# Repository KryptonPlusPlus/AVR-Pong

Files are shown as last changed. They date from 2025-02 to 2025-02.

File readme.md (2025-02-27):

<div align="center">

# AVR Pong
</div>

## 💻 Sobre o projeto

Jogo Pong de um jogador em um microcontrolador avr (atmega328pa) exibindo a imagem em um monitor vga de resolução 640x480 60Hz de tela visível.

Veja uma documentação não finalizada [aqui](documentation/doc/main.pdf).

> [!WARNING]
> Para aumentar a compatibilidade com os monitores foi utilizado um sistema de clock de 25.175MHz, superior ao limite recomendado pelo fabricante de 20MHz.

# :scroll: Sumário

- [Funcionalidades](#⚙️-Funcionalidades)
- [Imagens](#🎨-Imagens)

## ⚙️ Funcionalidades

- [ ] Colisão com os paddles.
    - [x] Tratar a colisão do eixo x.
    - [ ] Alterar a direção e/ou inclinação do eixo y da bola no momento da colisão com o paddle.
- [x] Aceleração da bola ao decorrer do jogo.
- [x] Reiniciar o jogo após errar a bola e apertar um botão.
- [ ] Pontuação dos jogadores.
- [ ] Som.
- [ ] Switch para realizar configurações internas.
- [ ] Indutor e capacitor no _AVCC_ para reduzir ruídos (pag. 213 do datasheet)

## 🎨 Imagens

<details>

<summary>Imagens da montagem do circuito na protoboard:</summary>

<p align="center">
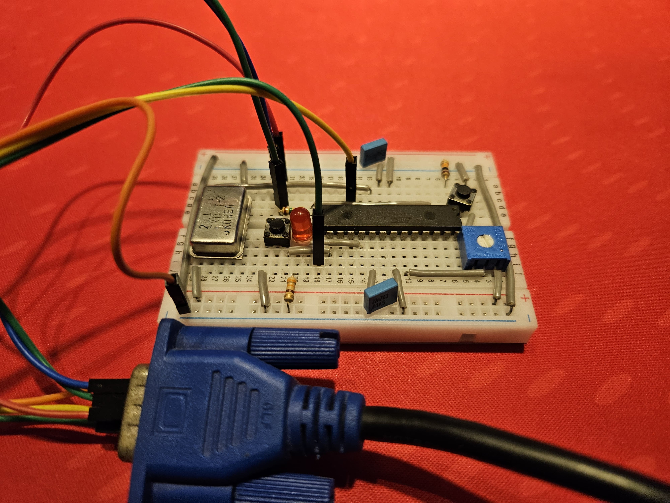
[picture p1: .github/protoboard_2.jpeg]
protoboard 1
    
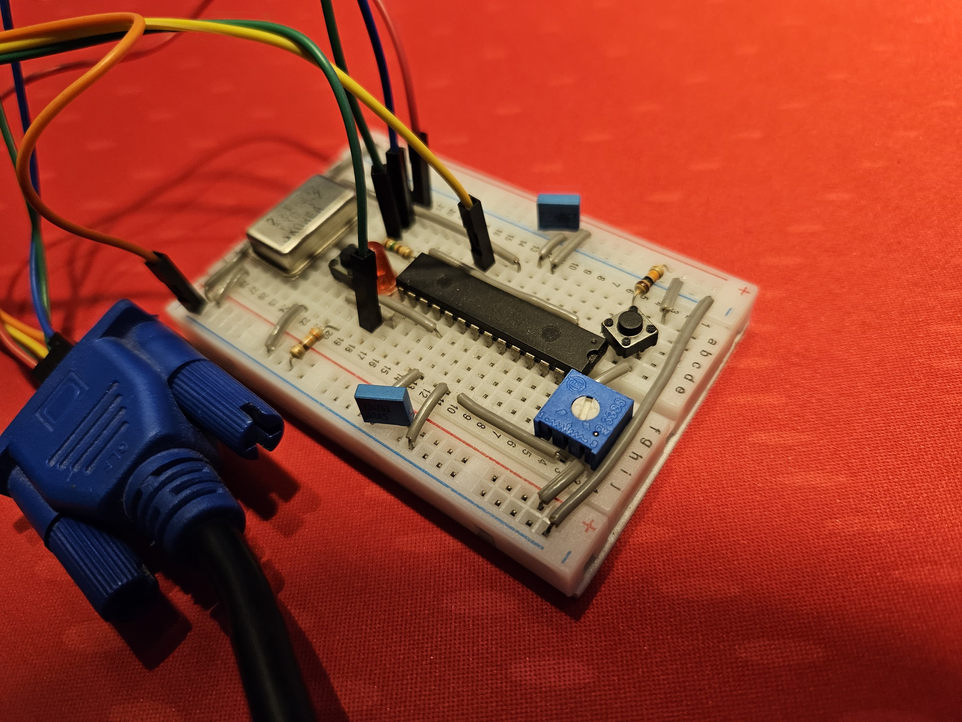
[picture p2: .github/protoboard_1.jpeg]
protoboard 2
    
</p>

> O _trimpot_ foi utilizado para movimentar o _paddle_ do jogador.

</details>

<details>

<summary>Imagem da renderização da tela no monitor vga:</summary>

<p align="center">
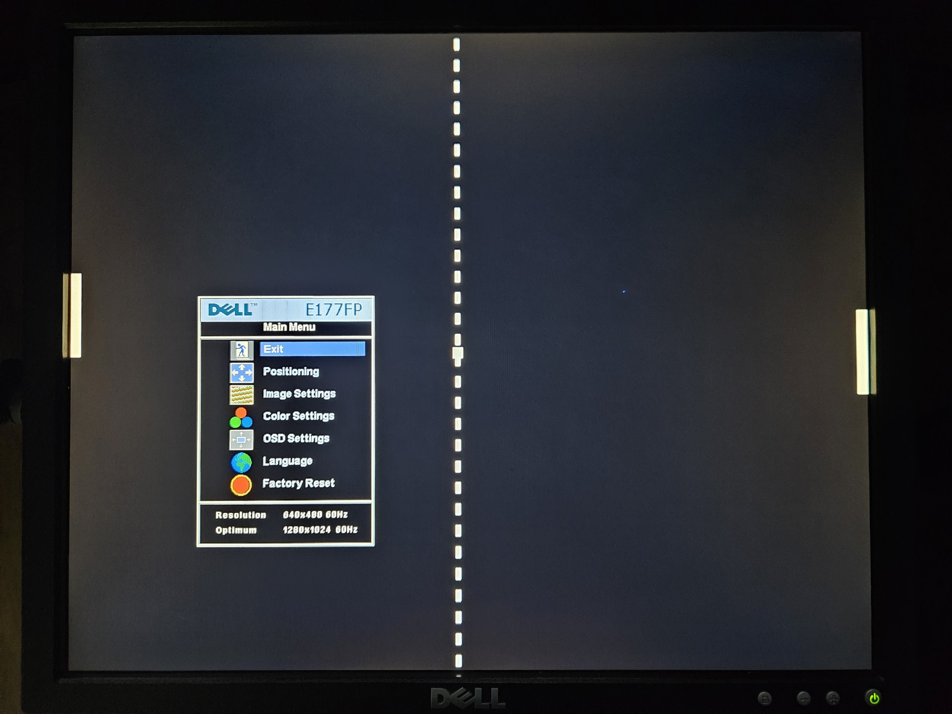
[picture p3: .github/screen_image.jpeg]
monitor
    
</p>

> Na imagem da renderização da tela existe uma linha vertical que não aparece, pois foi feita uma centralização da imagem pelas configurações no monitor, proveniente do fato da transferência dos dados das cores ser feita utilizando o _USART_ no modo _Master SPI_, já que quando ele está inativo possui nível lógico alto.

</details>

<details>

<summary>Imagem do esquemático:</summary>
<p align="center">
    monitor
</p>

</details>

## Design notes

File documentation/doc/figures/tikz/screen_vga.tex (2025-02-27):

\begin{figure}[H]
\centering
\resizebox{0.45\textwidth}{!}
{
\begin{tikzpicture}[x = .1mm, y = .1mm]
    
    \def\hvisiblearea {640}
    \def\vvisiblearea {480}
    
    \def\hfrontporch {16 * 2} % alterado para ficar mais estetico
    \def\vfrontporch {10 * 2} %

    \def\hsyncpulse {96}
    \def\vsyncpulse {2 * 4} % alterado para ficar mais estetico

    \def\hbackporch {48}
    \def\vbackporch {33}

    \begin{scope}[xshift = 5mm, local bounding box = pulse horizontal]
        \draw [black] (0, 0) -- ++(\hvisiblearea + \hfrontporch, 0) -- ++(0, -3.5mm) -- ++(\hsyncpulse, 0) -- ++(0, 3.5mm) -- ++(\hbackporch, 0);
        \node [above, font = \small] at (\hvisiblearea / 2, 0) {Pulso de sincronismo horizontal};
    \end{scope}

    \begin{scope}[yshift = -5mm, local bounding box = pulse vertical]
        \draw [black] (0, 0) -- ++(0, -\vvisiblearea - \vfrontporch) -- ++(3.5mm, 0) -- ++(0, -\vsyncpulse) -- ++(-3.5mm, 0) -- ++(0, -\vbackporch);
        \node [above, font = \small, rotate = 90] at (0, -\vvisiblearea / 2) {Pulso de sincronismo vertical};
    \end{scope}
    
    \begin{scope}[xshift = 5mm, yshift = -5mm, local bounding box = screen]
        % visible area
        \draw [black] (0, -\vvisiblearea) -- ++(\hvisiblearea, 0) -- ++(0, \vvisiblearea);
        % front porch
        \draw [black] (0, -\vvisiblearea - \vfrontporch) -- ++(\hvisiblearea + \hfrontporch, 0) -- ++(0, \vvisiblearea + \vfrontporch);
        % sync pulse
        \draw [black] (0, -\vvisiblearea - \vfrontporch - \vsyncpulse) -- ++(\hvisiblearea + \hfrontporch + \hsyncpulse, 0) -- ++(0, \vvisiblearea + \vfrontporch + \vsyncpulse);
        % back porch
        \draw [black] (0, 0) rectangle ++ (\hbackporch + \hvisiblearea + \hfrontporch + \hsyncpulse, -\vbackporch - \vvisiblearea - \vfrontporch - \vsyncpulse);
    
        %
        \node[above right = 0.8mm, font = \small, rotate = 90] at (\hvisiblearea, -\vvisiblearea) {\textit{Visible Area}};
        \node[above right = 0.8mm, font = \small, rotate = 90] at (\hvisiblearea + \hfrontporch, -\vvisiblearea) {\textit{Front Porch}};
        \node[above right = 0.8mm, font = \small, rotate = 90] at (\hvisiblearea + \hfrontporch + \hsyncpulse, -\vvisiblearea) {\textit{Sync Pulse}};
        \node[above right = 0.8mm, font = \small, rotate = 90] at (\hvisiblearea + \hfrontporch + \hsyncpulse + \hbackporch, -\vvisiblearea) {\textit{Back Porch}};
    \end{scope}

    \draw [gray, fill opacity = 0.5] (5mm,   -7.5mm) -- ++(0,    5mm);
    \draw [gray, fill opacity = 0.5] (7.5mm, -5mm)   -- ++(-5mm, 0);
\end{tikzpicture}
}
\caption{Regiões de varredura da tela}
\end{figure}

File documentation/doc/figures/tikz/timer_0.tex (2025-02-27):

\begin{figure}[H]
    \centering
    % https://wiki.physik.uzh.ch/cms/latex:tikz:electromagnetic_wave
    % https://tex.stackexchange.com/questions/550352/how-to-draw-a-simple-sine-square-sawtooth-waveform-in-latex
    \begin{tikzpicture}[line cap = round, line join = round, quotas/.style={very thin, |<->|}]
        %
        \def\Period{0.6\linewidth}
        \def\RampAmplitude{2.0}
        %
        \def\VericalOne{0.75 * \Period}
        \def\VericalTwo{\Period}

        % ramp
        \begin{scope}[local bounding box = ramp]
            \node [anchor = east, text width = 2cm, font = \small\itshape\bfseries] at (0, -\RampAmplitude) {tcnt0};
            \foreach \it/\txt in {0/ocr0a, -0.5/ocr0b, -2/bottom}
            {
                \draw [very thin, dotted] (0, \it) -- ++(1.16 * \Period, 0);
                \node [anchor = east, font = \footnotesize\itshape] at (0, \it) {\txt};
            }
   
            \draw (0, -\RampAmplitude) -- ++(\Period, \RampAmplitude) -- ++(0, -\RampAmplitude) -- ++(0.16 * \Period, 0.16 * \RampAmplitude);

        \end{scope}
        % pulse
        \begin{scope}[yshift = -2.5cm, local bounding box = pulse]
            \node [anchor = east, text width = 2cm, font = \small\itshape\bfseries] at (0, 0) {oc0b};
            \draw (0, 0) {-- ++(\VericalOne, 0) -- ++(0, -1) -- ++(\Period - \VericalOne, 0) -- ++(0, 1) -- ++(0.16 * \Period, 0)};
        \end{scope}

        \def\lastx{0}
        \foreach[count = \i, remember = \it as \lastxit] \it/\initpos in {\VericalOne/-0.5,\VericalTwo/0}
        {
             \draw [very thin, dotted] (\it, \initpos) -- (\it,   -4);
             \draw [very thin, dotted] (\it, \initpos) -- (\it,   -4);
             \draw [quotas] (\lastxit, -4) -- node[inner sep = 1pt, fill = white, font = \scriptsize] {\i} (\it,  -4);
        }
    \end{tikzpicture}
    \caption{Funcionamento do \textit{Timer 0} (\textit{Hsync})}
    \label{fig:timer-0}
\end{figure}

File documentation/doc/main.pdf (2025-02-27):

## AVR Pong

KrpytonPlusPlus

27 de fevereiro de 2025

## 1 Introdução

Esse projeto visa projetar um clone do jogo Pong em um microcontrolador avr utilizando o padrão de comunicação vga para exibir a imagem em um monitor.
Para isso foi dimensionado os ciclos de cpu para comportar o envio das informações de varredura dos pixels e os ciclos sobressalentes foram utilizados para carregar os dados para os buffers com as cores de cada pixel em uma linha (preto ou branco) e fazer o tratamento das iterações do jogo.
Buscando facilitar os cálculos e aumentar a compatibilidade com os monitores foi utilizado um sistema de clock de 25,175MHz para o microcontrolador superior ao limite estipulado pelo fabricante no manual, porém como vai ser visto adiante é a mesma frequência de sinal utilizada pelo monitor para gerar a imagem.

## 2 VGA (Video Graphics Array)

### 2.1 Regiões de varredura

Pulso de sincronismo horizontal

Pulso de sincronismo vertical

Visible Area
Front Porch
Sync Pulse

Back Porch

Figura 1: Regiões de varredura da tela

No monitor normalmente a Back Porch vem antes da Visible Area, porém para facilitar a apresentação e por ser um sinal cíclico foi apresentada no final. Para facilitar a visualização as dimensões de cada região não estão proporcionais aos valores reais.

Pixels
| Horizontal | Vertical
Back Porch | 48 | 33
Visible Area | 640 | 480
Front Porch | 16 | 10
Sync Pulse | 96 | 2
Total | 800 | 525

Tabela 1: Dimensão horizontal e vertical em pixels da tela para cada região de varredura

Normalmente os dados apresentados na tabela 1 são dados em micro segundos e quantidade de linhas, para a dimensão horizontal e vertical, respectivamente.

### 2.2 Pulsos de sincronismo

Os pulsos verticais são formados utilizando o Timer 1 no modo fast pwm com top sendo o icr1 (wgm1[3:0] = 1410) e utilizando um prescaling com valor 8 (cs1[2:0] = 210), a escolha desse Timer foi feita pelo fato de possuir um contador de 16 bits. O timer possui 3 registradores de comparação (ocr1a, ocr1b e icr1), sendo dois de saída, para poder realizar a construção do pulso, utilizando o modo de comparação para quando o contador atingir o valor de ocr1a a saída ir para nível lógico baixo e quando voltar para bottom ir para nível lógico alto (com1a[1:0] = 210) e o terceiro, de entrada, para determinar o inicio da área visível da tela.

tcnt1

icr1
ocr1a

ocr1b
bottom
oc1a
1 | 2 | 3

Figura 2: Funcionamento do Timer 1 (Vsync)

Na figura é possível ver o funcionamento esperado da saída oc1a em função do contador tcnt1, as regiões 1, 2 e 3 são respectivamente, Vertical Back Porch, Vertical Visible Area junto com a Vertical Front Porch e Vertical Sync Pulse.

Os valores de comparação da contagem são dados a seguir:

icr1 | 52499
ocr1a | 52299
ocr1b | 3199

Tabela 2: Valores dos registradores de comparação do Timer 1

O valor do ocr1b foi calculado para uma linha a menos, para evitar conflitos com os pulsos horizontais, pois quando o seu valor é atingido ocorre uma interrupção para um função que ativa a interrupção para o Timer 0 em ocr0a, que será desativada dentro do próprio algoritmo da função chamada pela comparação.
Em que icr1, por exemplo, é calculado da seguinte forma:

800 · 525
8
− 1 = 52499 | (1)

Pelo fato do clock utilizado ser de 25,175MHz, igual a frequência dos pixels para o padrão de resolução utilizado, os valores de comparação são numericamente iguais menos um a contagem dos pixels, pelo fato da contagem iniciar em zero, considerando o valor do prescaling.
Os pulsos horizontais são formados pelo Timer 0, deixando o Timer 2 livre, no modo fast pwm com top sendo o ocr0a (wgm0[2:0] = 710) e utilizando prescaling com valor 8 (cs0[2:0] = 210). Esse Timer possui dois registradores de comparação (ocr0a, ocr0b) utilizados para criar um pulso de polaridade negativa entre eles.
Durante o overflow do contador ocorre uma chamada de interrupção que faz o tratamento da região horizontal Back Porch e da área visível, realizando o envio dos pixels e durante a região Front Porch e Sync Pulse ocorre a construção do buffer da próxima linha.

tcnt0

ocr0a

ocr0b

bottom
oc0b
1 | 2

Figura 3: Funcionamento do Timer 0 (Hsync)

Na figura é possível ver o funcionamento esperado da saída oc0b em função do contador tcnt0, as regiões 1 e 2 são respectivamente, horizontal Back Porch junto com a Visible Area e a Front Porch, e a Sync Pulse.

Os valores de comparação da contagem são dados a seguir:

ocr0a | 99
ocr0b | 87

Tabela 3: Valores dos registradores de comparação do Timer 0

Em que o calculo é similar ao realizado para o comparadores do pulso vertical, como é possível ver a seguir para o ocr0a, por exemplo:

800
8
− 1 = 99 | (2)

### 2.3 Varredura dos pixels

Para realizar a varredura dos pixels foi utilizado o protocolo de comunicação usart no modo master spi do microcontrolador, pelo fato de ser possível fazer uma comunicação de no máximo duas vezes mais lenta que o clock do sistema de forma autônoma, e por ter a mesma frequência dos pixels implica que a resolução horizontal é reduzida pela metade, porém ocupando a mesma quantidade de pixels.

A comunicação é feita pela conexão txd e o hardware utiliza a conexão xck como clock de sincronismo, mesmo que ele não seja utilizado.

## 3 Pong

O jogo Pong se baseia em lançar uma bola de um lado ao outro da tela com uma "raquete"(paddle) tentando fazer com que o outro jogador erre a bola assim ganhando um ponto, parecido com o ping pong, porém esse projeto se baseia em apenas um jogador, portanto o outro paddle apenas segue a bola, e os elementos do jogo possuem algumas iterações com entre si, por exemplo sempre que a bola atinge o paddle da esquerda ela aumenta a velocidade além de possuir trajetórias diferentes dependendo de onde acertar.

A disposição dos elementos do jogo é apresentada na figura 4, onde é possível observar os dois paddles, a bola, a linha divisória central e a pontuação de cada jogador.

Figura 4: Janela do jogo

As dimensões de cada elemento da janela segue os valores apresentados na tabela 4, para o tracejado central esse é o valor de cada traço:

| H (Pixels) | V (Linhas)
Janela | 640 | 480
Paddle | 8 | 63
Bola | 8 | 8
Tracejado central | 4 | 6

Tabela 4: Dimensão de cada objeto, em que H é o tamanho horizontal e V é o tamanho vertical.

Como já apresentado, a bola possui trajetórias diferentes dependendo de onde ela atinge o paddle, quanto mais afastado do centro maior será o ângulo entre a normal e a trajetória refletida, na mesma direção de crescimento do paddle, em que no centro esse valor é igual a zero, como é possível ver na figura 5:

Figura 5: Colisões no paddle (as setas funcionam de forma simétrica)

## Referências

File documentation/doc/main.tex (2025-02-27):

\documentclass[twocolumn]{article}

\usepackage[a4paper, top    = 2.5cm, 
                     bottom = 2.0cm, 
                     left   = 2.5cm, 
                     right  = 2.0cm]{geometry}

\usepackage[brazil]{babel}
\usepackage[T1]{fontenc}
\usepackage{microtype}

\usepackage{indentfirst}

\usepackage{float}

\usepackage{tikz}
\tikzset{>=latex} % for LaTeX arrow head

\title{AVR Pong}
\author{KrpytonPlusPlus}

\begin{document}

\maketitle

\section{Introdução}
    Esse projeto visa projetar um clone do jogo \textsl{Pong} em um microcontrolador \textsl{avr} utilizando o padrão de comunicação \textsl{vga} para exibir a imagem em um monitor.

    Para isso foi dimensionado os ciclos de \textsl{cpu} para comportar o envio das informações de varredura dos \textsl{pixels} e os ciclos sobressalentes foram utilizados para carregar os dados para os \textsl{buffers} com as cores de cada pixel em uma linha (preto ou branco) e fazer o tratamento das iterações do jogo.

    Buscando facilitar os cálculos e aumentar a compatibilidade com os monitores foi utilizado um sistema de \textsl{clock} de \(25{,}175MHz\) para o microcontrolador superior ao limite estipulado pelo fabricante no manual, porém como vai ser visto adiante é a mesma frequência de sinal utilizada pelo monitor para gerar a imagem.

\section{VGA (Video Graphics Array)}
    \subsection{Regiões de varredura}
    
    \input{figures/tikz/screen_vga}

    No monitor normalmente a \textsl{Back Porch} vem antes da \textsl{Visible Area}, porém para facilitar a apresentação e por ser um sinal cíclico foi apresentada no final.

    Para facilitar a visualização as dimensões de cada região não estão proporcionais aos valores reais.
    
    \begin{table}[H]
        \centering
        \begin{tabular}{r c c}                                            \cline{2-3}
                                  & \multicolumn{2}{c}{\textsl{Pixels}} \\\cline{2-3}
                                  & Horizontal      & Vertical          \\\hline
            \textsl{Back Porch}   & 48              & 33                \\
            \textsl{Visible Area} & 640             & 480               \\
            \textsl{Front Porch}  & 16              & 10                \\
            \textsl{Sync Pulse}   & 96              & 2                 \\
            Total                 & 800             & 525               \\\hline
        \end{tabular}
        \caption{Dimensão horizontal e vertical em \textsl{pixels} da tela para cada região de varredura}
        \label{tab:dimensions_scanning_regions}
    \end{table}

    Normalmente os dados apresentados na tabela \ref{tab:dimensions_scanning_regions} são dados em micro segundos e quantidade de linhas, para a dimensão horizontal e vertical, respectivamente.
    
    \subsection{Pulsos de sincronismo}
        Os pulsos verticais são formados utilizando o \textsl{Timer 1} no modo \textsl{fast pwm} com \textsl{top} sendo o \textsl{icr1} (\textsl{wgm1[3:0] = 14\(_{10}\)}) e utilizando um \textsl{prescaling} com valor 8 (\textsl{cs1[2:0] = 2\(_{10}\)}), a escolha desse \textsl{Timer} foi feita pelo fato de possuir um contador de 16 \textsl{bits}. O \textsl{timer} possui 3 registradores de comparação (\textsl{ocr1a}, \textsl{ocr1b} e \textsl{icr1}), sendo dois de saída, para poder realizar a construção do pulso, utilizando o modo de comparação para quando o contador atingir o valor de \textsl{ocr1a} a saída ir para nível lógico baixo e quando voltar para \textsl{bottom} ir para nível lógico alto (\textsl{com1a[1:0] = 2\(_{10}\)}) e o terceiro, de entrada, para determinar o inicio da área visível da tela.

        \input{figures/tikz/timer_1}

        Na figura é possível ver o funcionamento esperado da saída \textsl{oc1a} em função do contador \textsl{tcnt1}, as regiões 1, 2 e 3 são respectivamente, \textsl{Vertical Back Porch}, \textsl{Vertical Visible Area} junto com a \textsl{Vertical Front Porch} e \textsl{Vertical Sync Pulse}. % TODO: deixar em portugues

        Os valores de comparação da contagem são dados a seguir:
        
        \begin{table}[H]
            \centering
            \begin{tabular}{l l}           \hline
                \textsl{icr1}   & 52499 \\ \hline
                \textsl{ocr1a}  & 52299 \\ \hline
                \textsl{ocr1b}  & 3199  \\ \hline
            \end{tabular}
            \caption{Valores dos registradores de comparação do \textsl{Timer 1}}
            \label{tab:val_timer_1_Hsync}
        \end{table}

        O valor do \textsl{ocr1b} foi calculado para uma linha a menos, para evitar conflitos com os pulsos horizontais, pois quando o seu valor é atingido ocorre uma interrupção para um função que ativa a interrupção para o \textsl{Timer 0} em \textsl{ocr0a}, que será desativada dentro do próprio algoritmo da função chamada pela comparação.

        Em que \textsl{icr1}, por exemplo, é calculado da seguinte forma:
        
        \begin{equation}
            \frac{800 \cdot 525}{8} - 1 = 52499
        \end{equation}
        
        Pelo fato do \textsl{clock} utilizado ser de \(25{,}175 MHz\), igual a frequência dos \textsl{pixels} para o padrão de resolução utilizado, os valores de comparação são numericamente iguais menos um a contagem dos \textsl{pixels}, pelo fato da contagem iniciar em zero, considerando o valor do \textsl{prescaling}.
        
        Os pulsos horizontais são formados pelo \textsl{Timer 0}, deixando o \textsl{Timer 2} livre, no modo \textsl{fast pwm} com \textsl{top} sendo o \textsl{ocr0a} (\textsl{wgm0[2:0] = 7\(_{10}\)}) e utilizando \textsl{prescaling} com valor 8 (\textsl{cs0[2:0] = 2\(_{10}\)}). Esse \textsl{Timer} possui dois registradores de comparação (\textsl{ocr0a}, \textsl{ocr0b}) utilizados para criar um pulso de polaridade negativa entre eles.

        Durante o \textsl{overflow} do contador ocorre uma chamada de interrupção que faz o tratamento da região horizontal \textsl{Back Porch} e da área visível, realizando o envio dos \textsl{pixels} e durante a região \textsl{Front Porch} e \textsl{Sync Pulse} ocorre a construção do \textsl{buffer} da próxima linha.
        
        \input{figures/tikz/timer_0}

        Na figura é possível ver o funcionamento esperado da saída \textsl{oc0b} em função do contador \textsl{tcnt0}, as regiões 1 e 2 são respectivamente, horizontal \textsl{Back Porch} junto com a \textsl{Visible Area} e a \textsl{Front Porch}, e a \textsl{Sync Pulse}.

        Os valores de comparação da contagem são dados a seguir:
        
        \begin{table}[H]
            \centering
            \begin{tabular}{l l}        \hline
                \textsl{ocr0a}  & 99 \\ \hline
                \textsl{ocr0b}  & 87 \\ \hline
            \end{tabular}
            \caption{Valores dos registradores de comparação do \textsl{Timer 0}}
            \label{tab:val_timer_0}
        \end{table}

        Em que o calculo é similar ao realizado para o comparadores do pulso vertical, como é possível ver a seguir para o \textsl{ocr0a}, por exemplo:
    
        \begin{equation}
             \frac{800}{8} - 1 = 99
        \end{equation}

    \subsection{Varredura dos \textsl{pixels}}
        Para realizar a varredura dos \textsl{pixels} foi utilizado o protocolo de comunicação \textsl{usart} no modo master \textsl{spi} do microcontrolador, pelo fato de ser possível fazer uma comunicação de no máximo duas vezes mais lenta que o \textsl{clock} do sistema de forma autônoma, e por ter a mesma frequência dos \textsl{pixels} implica que a resolução horizontal é reduzida pela metade, porém ocupando a mesma quantidade de \textsl{pixels}.
        
        A comunicação é feita pela conexão \verb|txd| e o \verb|hardware| utiliza a conexão \textsl{xck} como \textsl{clock} de sincronismo, mesmo que ele não seja utilizado.
        
\section{\textsl{Pong}}

    O jogo \textsl{Pong} se baseia em lançar uma bola de um lado ao outro da tela com uma "raquete" (\textsl{paddle}) tentando fazer com que o outro jogador erre a bola assim ganhando um ponto, parecido com o \textsl{ping pong}, porém esse projeto se baseia em apenas um jogador, portanto o outro \textsl{paddle} apenas segue a bola, e os elementos do jogo possuem algumas iterações com entre si, por exemplo sempre que a bola atinge o \textsl{paddle} da esquerda ela aumenta a velocidade além de possuir trajetórias diferentes dependendo de onde acertar.

    A disposição dos elementos do jogo é apresentada na figura \ref{fig:game_screen}, onde é possível observar os dois \textsl{paddles}, a bola, a linha divisória central e a pontuação de cada jogador.
    
    \input{figures/tikz/screen_pong}

    As dimensões de cada elemento da janela segue os valores apresentados na tabela \ref{tab:dimension_screen_game}, para o tracejado central esse é o valor de cada traço:
    
    \begin{table}[H]
        \centering
        \begin{tabular}{l c c}                                   \\ \cline{2-3}
                              & H (\textsl{Pixels}) & V (Linhas) \\ \hline
            Janela            & 640                 & 480        \\ 
            \textsl{Paddle}   & 8                   & 63         \\ 
            Bola              & 8                   & 8          \\
            Tracejado central & 4                   & 6          \\ \hline
        \end{tabular}
        \caption{Dimensão de cada objeto, em que H é o tamanho horizontal e V é o tamanho vertical.}
        \label{tab:dimension_screen_game}
    \end{table}

    Como já apresentado, a bola possui trajetórias diferentes dependendo de onde ela atinge o \textsl{paddle}, quanto mais afastado do centro maior será o ângulo entre a normal e a trajetória refletida, na mesma direção de crescimento do \textsl{paddle}, em que no centro esse valor é igual a zero, como é possível ver na figura \ref{fig:collisions_paddle}:
    
    \input{figures/tikz/paddle_collision}

    \bibliographystyle{unsrt}
    \bibliography{ref}

\end{document}

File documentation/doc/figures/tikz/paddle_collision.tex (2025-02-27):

\begin{figure}[H]
\centering
    % 0b11_111
\begin{tikzpicture}[x = 1mm, y = 1mm, scale = .6]
    \begin{scope}[xshift = 20mm, local bounding box = paddle]
        \draw [black] (0, 0) rectangle ++(8, 63);

        \draw [black] (0, 7 * 63 / 8) -- ++(8, 0);
        \draw [black] (0, 6 * 63 / 8) -- ++(8, 0);
        \draw [black] (0, 5 * 63 / 8) -- ++(8, 0);
        \draw [black] (0, 4 * 63 / 8) -- ++(8, 0);
        \draw [black] (0, 3 * 63 / 8) -- ++(8, 0);
        \draw [black] (0, 2 * 63 / 8) -- ++(8, 0);
        \draw [black] (0, 1 * 63 / 8) -- ++(8, 0);
    \end{scope}

    \begin{scope}[xshift = 0, local bounding box = lines]
        % 3
        \draw [gray, -, dashed]  (0,  8 * 63 / 8 - 4) -- ++(20,  0);
        \draw [black, ->]  (20, 8 * 63 / 8 - 4) -- ++(-20, 15);
        % 2
        \draw [gray, -, dashed]  (0,  7 * 63 / 8 - 4) -- ++(20,  0);
        \draw [black, ->]  (20, 7 * 63 / 8 - 4) -- ++(-20, 7);
        % 1
        \draw [gray, -, dashed]  (0,  6 * 63 / 8 - 4) -- ++(20,  0);
        \draw [black, ->]  (20, 6 * 63 / 8 - 4) -- ++(-20, 3);
        % 0 
        \draw [gray, -, dashed]  (0,  5 * 63 / 8 - 4) -- ++(20,  0);
        \draw [black, <-] (0, 5 * 63 / 8 - 4)  -- ++(20,  0);
    \end{scope}

    \draw [gray, fill opacity = 0.5] (20, 4 * 63 / 8 + 2) -- ++(0, -4);
    \draw [gray, fill opacity = 0.5] (18, 4 * 63 / 8)     -- ++(4, 0);
    
\end{tikzpicture}
\caption{Colisões no \textit{paddle} (as setas funcionam de forma simétrica)}
\label{fig:collisions_paddle}
\end{figure}

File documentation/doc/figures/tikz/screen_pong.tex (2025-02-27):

\begin{figure}[H]
\centering
\resizebox{0.45\textwidth}{!}
{
\begin{tikzpicture}[x = 1mm, y = 1mm]
    
    \def\width  {640}
    \def\height {480}

    % screen
    \path [fill = black] (1, 1) rectangle ++(\width, \height);
    % paddle 1
    \path [fill = white] (1 - 1, \height / 2 - 32) rectangle ++(8 - 1, 63 - 1);
    % paddle 2
    \path [fill = white] (\width - 8 + 1, \height / 2 - 32) rectangle ++(8, 63);
    % ball
    \path [fill = white] (160, 320) rectangle ++(8, 8);
    % Number 1
    \path [fill = white] (\width / 4 - 16, \height - 32) 
        rectangle ++(32 - 1,   8 - 1)
        rectangle ++(8 - 1,  -64 + 1)
        rectangle ++(-32 + 1, -8 + 1)
        rectangle ++(-8 + 1,  64 - 1);
    % Number 2
    \path [fill = white] (3 * \width / 4 - 16, \height - 32) 
        rectangle ++(32 - 1,   8 - 1)
        rectangle ++(8 - 1,  -64 + 1)
        rectangle ++(-32 + 1, -8 + 1)
        rectangle ++(-8 + 1,  64 - 1);
        
    % middle line
    \foreach \i in {1, 16, ..., \height}
         \path [fill = white] (\width / 2 - 4, \i + 3) rectangle ++(4 - 1, 8 - 1);

\end{tikzpicture}
}
\caption{Janela do jogo}
\label{fig:game_screen}
\end{figure}

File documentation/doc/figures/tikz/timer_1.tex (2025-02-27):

\begin{figure}[H]
    \centering
    % https://wiki.physik.uzh.ch/cms/latex:tikz:electromagnetic_wave
    % https://tex.stackexchange.com/questions/550352/how-to-draw-a-simple-sine-square-sawtooth-waveform-in-latex
    \begin{tikzpicture}[line cap = round, line join = round, quotas/.style={very thin, |<->|}]
        %
        \def\Period{0.6\linewidth}
        \def\RampAmplitude{2.0}
        %
        \def\VericalOne{0.13 * \Period}
        \def\VericalTwo{0.88 * \Period}
        \def\VericalThree{\Period}

        % ramp
        \begin{scope}[local bounding box = ramp]
            \node [anchor = east, text width = 2cm, font = \small\itshape\bfseries] at (0, -\RampAmplitude) {tcnt1};
            \foreach \it/\txt in {0/icr1, -0.24/ocr1a, -1.75/ocr1b, -2/bottom}
            {
                \draw [very thin, dotted] (0, \it) -- ++(1.16 * \Period, 0);
                \node [anchor = east, font = \footnotesize\itshape] at (0, \it) {\txt};
            }
   
            \draw (0, -\RampAmplitude) {-- ++(\Period, \RampAmplitude) -- ++(0, -\RampAmplitude) -- ++(0.16 * \Period, 0.16 * \RampAmplitude)} ;
        \end{scope}
        % pulse
        \begin{scope}[yshift = -2.5cm, local bounding box = pulse]
            \node [anchor = east, text width = 2cm, font = \small\itshape\bfseries] at (0, 0) {oc1a};
            \draw (0, 0) {-- ++(\VericalTwo, 0) -- ++(0, -1) -- ++(\Period - \VericalTwo, 0) -- ++(0, 1) -- ++(0.16 * \Period, 0)};
        \end{scope}

        \def\lastx{0}
        \foreach[count = \i, remember = \it as \lastxit] \it/\initpos in {\VericalOne/-1.75, \VericalTwo/-0.24,\VericalThree/0}
        {
            \draw [very thin, dotted] (\it, \initpos) -- (\it,   -4);
            \draw [very thin, dotted] (\it, \initpos) -- (\it,   -4);
            \draw [quotas] (\lastxit, -4) -- node[inner sep = 1pt, fill = white, font = \scriptsize] {\i} (\it,  -4);
        }
    \end{tikzpicture}
    \caption{Funcionamento do \textit{Timer 1} (\textit{Vsync})}
    \label{fig:timer-1}
\end{figure}

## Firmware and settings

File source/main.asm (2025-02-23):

; Clock 25.175Mhz

;
;	Video Resolution:		320 x 480 @ 60 Hz
;
; Video setup VGA 
;     Video Resolution:		VGA Signal 640 x 480 @ 60 Hz Industry standard timing
;     Colors:				1 Color (white)
; Hardware
;     ATMEL ATMEGA328P-PU
;
; Created:     27/01/2025
; Last Update: xx/xx/2025

;  
;         0    |    0
;
;              |    *
;   |                      |
;              |
;
;              |
;


.include "m328Pdef.inc"					; include defs Atmega328p
.include "def.inc"						; include program defs

.include "vars.asm"

.cseg
; --- table vectors ---
.org	0x0000
	rjmp	start

.org	0x0018							; 
	rjmp	end_vertical_back_porch		; timer1_compb

.org	0x001c							;
	rjmp	handle_vga_line				; timer0_compa
; ---

; --- init start ---
.org	0x0034
start:
	cli

	.include	"setup.asm"

	sei

; --- init loop ---
loop:
	; --- sleep ---
	;in		r16,	smcr				; smcr is 0x00 (idle sleep mode)
	out		smcr,	one_reg				;							; 1c
	sleep								;							; 1c
	out		smcr,	zero_reg			; sleep cpu
	; ---
	lds		r16,	timsk0											; 2c
	cpse	r16,	zero_reg										; 1c +1c if true
	rjmp	loop						; infinite loop				; 2c

	.include "pong.asm"
	rjmp	loop
; --- 

; --- interrupt call ---
end_vertical_back_porch:											; 2c + 4c
	; Vertical Visible area
    ; ativa a rotina de tratar e imprimir os pixels dentro 
	; da area vertical visivel,
	; é desativado dentro da propria rotina
	ldi		r16,	1<<ocie0a			; enable timer 0 			; 1c
	sts		timsk0,	r16					; compare in ocr0a			; 2c

	reti															; 4c
; ---

; ---

; --- interrupt call (handle_vga_line) ---
end_visible_area:
	sts		timsk0,	zero_reg										; 2c
	
	out 	counterh,	zero_reg									; 1c
	out 	counterl,	zero_reg									; 1c

	reti															; 4c

	; 2c + 4c
handle_vga_line:													
	; -- Horizontal Back Porch (48c - 6c max) ---
	in		r25,	counterh										; 1c
	in		r24,	counterl										; 1c

	adiw	r25:r24,	0x01										; 2c

	out 	counterh,	r25											; 1c
	out 	counterl,	r24											; 1c

	; --- load counter line ---
	; chamada do counter para depois do line_scan_loop
	; economia de ciclos
	in		r27,	counterh										; 1c
	in		r26,	counterl										; 1c
	; ---

	subi	r24,	low (481)										; 1c 
	sbci 	r25,	high(481)										; 1c \_ +1c if true
	brpl	end_visible_area										; 1c /

	ldi		zh,		high(line_buffer + 39 + 2)	; TODO:					; 1c 
	ldi		zl,		low (line_buffer + 39 + 2)	; load buffer address	; 1c

	ld		r16,	-z		; carrega o primeiro valor no reg antes	; 2c
	
	ldi 	r17,	buffer_size										; 1c

	; melhora a linha vertical inicial
	sts		udr0,	zero_reg			; first value zero			; 2c
	ldi		r18,	1<<txen0			; 							; 1c
	sts		ucsr0b,	r18					; enable transmission		; 2c

	; tempo para carregar a primeira linha vazia
	nop nop nop nop nop nop nop nop nop nop nop nop nop nop

	; ---
line_scan_loop:
	; --- pixel printing routine --- 
	; 640 / (8 * 2) = 40 bytes

	; gastando tempo para realizar o shift left do udr0
	; 8 bits -> 8 shifts (clk/2 shift) -> 16c, considerando o sts

	sts		udr0,	r16												; 2c
	
	nop																; 1c
	nop																; 1c
	nop																; 1c
	nop																; 1c
	nop																; 1c
	nop																; 1c
	nop																; 1c 
	
	st		z,		zero_reg			; clear last byte buffer	; 2c

	ld		r16,	-z												; 2c

	dec		r17														; 1c \_ +1c if true
	brne	line_scan_loop											; 1c /

	sts		ucsr0b,	zero_reg			; disable tx 				; 1c
	; ---

	.include "handle_line_buffer.asm"
; ---

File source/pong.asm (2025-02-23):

    sbic    pong_state, run
    rjmp    run_pong

    ldi     r16,    low (v_res / 2)
    ldi     r17,    high(v_res / 2)
    mov     ball_position_yh,   r17     ; 
    mov     ball_position_yl,   r16     ; reset position y

    ldi     r16,    low (h_res / 4 + 8 + ball_size / 2 - 1)
    ldi     r17,    high(h_res / 4 + 8 + ball_size / 2 - 1)
    mov     ball_position_xh,   r17     ; 
    mov     ball_position_xl,   r16     ; reset position x

    ; reset pong_state
    ldi      r16,   (1<<velx0)|(1<<vely0)
    out     pong_state, r16

    sbis    pinb,   pb2                 ; if press button
    sbi     pong_state, run
    
run_pong:
    ; --- init adc ---
    ; 25c
    lds     r16,    adcsra
    ori     r16,    1<<adsc
    sts     adcsra, r16
    ; --- 

    ; --- move ball x ---
	movw	r25:r24,	ball_position_xh:ball_position_xl			; 1c
    
    subi    r24,    low (paddle_displacement)
    sbci    r25,    high(paddle_displacement)
    brge    x_1

    sbi     pong_state, dirx
x_1:
	movw	r25:r24,	ball_position_xh:ball_position_xl			; 1c

    subi    r24,    low ((h_res / 2) - (ball_size / 2))
    sbci    r25,    high((h_res / 2) - (ball_size / 2))
    brlt    x_2

    ; so precisa fazer o teste de colisao para o paddle da esquerda
    ; o outro segue a bola, logo sempre vai acertar

    movw	r25:r24,    ball_position_yh:ball_position_yl

    cbi     pong_state, run   

    sub     r24,    paddle_pos_2l
    sbc     r25,    paddle_pos_2h
    brlt    end_collision_paddle

    subi    r24,    low (paddle_size - ball_size / 2)
    sbci    r25,    high(paddle_size - ball_size / 2)
    brge    end_collision_paddle

    ; acertou o paddle, continua o jogo
    sbi     pong_state, run
    ; aumenta a velocidade x sempre q acerta o paddle
    in      r16,    pong_state
   
    andi    r16,    velxmax             ; testa se atingiu a velocidade máxima
    subi    r16,    velxmax             ; 0bxxx111xx
    breq    end_collision_paddle
    
    in      r16,    pong_state
    subi    r16,    -(1<<velx0)         ; adiciona 1 na velocidade x
    out     pong_state, r16

end_collision_paddle:

    cbi     pong_state, dirx
x_2:
    in      r16,    pong_state          ;
    lsr     r16                         ;
    lsr     r16                         ;
    andi    r16,    0b111               ; get x velocity

    sbic    pong_state, dirx
    ldi     r17,    0x00 

    sbis    pong_state, dirx
    neg     r16
    sbis    pong_state, dirx
    ldi     r17,    0xff

    add     ball_position_xl,    r16
    adc     ball_position_xh,    r17 
    ; ---

    ; --- move ball y --- 
    movw	r25:r24,    ball_position_yh:ball_position_yl  			; 1c

    subi    r24,    0                   ;
    sbci    r25,    0                   ;
    brge    y_1                         ; teste vertical em 0

    sbi     pong_state, diry
y_1:
    movw	r25:r24,    ball_position_yh:ball_position_yl  			; 1c

    subi    r24,    low (v_res - ball_size) ;
    sbci    r25,    high(v_res - ball_size) ;
    brlt    y_2                             ; teste vertical em v_res - ball_size

    cbi     pong_state, diry    
y_2:
    in      r16,    pong_state              ;
    andi    r16,    (1<<vely1)|(1<<vely0)   ; get y velocity

    sbic    pong_state, diry
    ldi     r17,    0x00 

    sbis    pong_state, diry            ;
    neg     r16                         ;
    sbis    pong_state, diry            ;
    ldi     r17,    0xff                ; complemento de dois

    add     ball_position_yl,   r16
    adc     ball_position_yh,   r17 
    ; ---

    ; --- move paddle_1 --- 
    movw	r25:r24,	ball_position_yh:ball_position_yl			; 1c
    sbiw    r25:r24,    paddle_size / 2 - ball_size / 2

    movw	r27:r26,	ball_position_yh:ball_position_yl			; 1c
    
    sbiw    r27:r26,    paddle_size / 2
    brge    paddle_top_test_1

    ldi     r25,        0
    ldi     r24,        0

paddle_top_test_1:
    subi    r26,        low (v_res - paddle_size)   ; ja foi feita uma sub de
    sbci    r27,        high(v_res - paddle_size)   ; paddle_size / 2
    brlt    paddle_lower_test_1

    ldi     r24,        low (v_res - paddle_size)
    ldi     r25,        high(v_res - paddle_size)

paddle_lower_test_1:
    movw    paddle_pos_1h:paddle_pos_1l,    r25:r24
    ; ---   

    ; --- move paddle_2 ---
    ; paddle range        [0 : vres - paddle_size - 1] = [0 : 416]
    ; potentiometer range [0 : 511 * 0.8125] = [0 : 415.18]
    ; 0.8125 = 1 - 1/8 - 1/16
    lds     r24,    adcl
    lds     r25,    adch

    lsr     r25                         ; 
    ror     r24                         ; adc / 2 -> [0 : 511]
    
    movw    r27:r26,    r25:r24

    lsr     r27                         ; 
    ror     r26                         ; 
    lsr     r26                         ; 
    lsr     r26                         ; r27:r26 / 8

    sub     r24,    r26                 ;
    sbc     r25,    r27                 ; 1 - 1/8

    lsr     r26                         ; r27:r26 / 16

    sub     r24,    r26                 ;
    sbc     r25,    r27                 ; 1 - 1/8 - 1/16

    movw	paddle_pos_2h:paddle_pos_2l,	r25:r24
    ; ---
